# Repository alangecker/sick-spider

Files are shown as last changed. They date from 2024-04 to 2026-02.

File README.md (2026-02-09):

# SICK Spider
A new board design for the amazing [COATI Spider project](https://coati.pimienta.org/electronics/spider/), a small portable device for simultaneous interpretation.

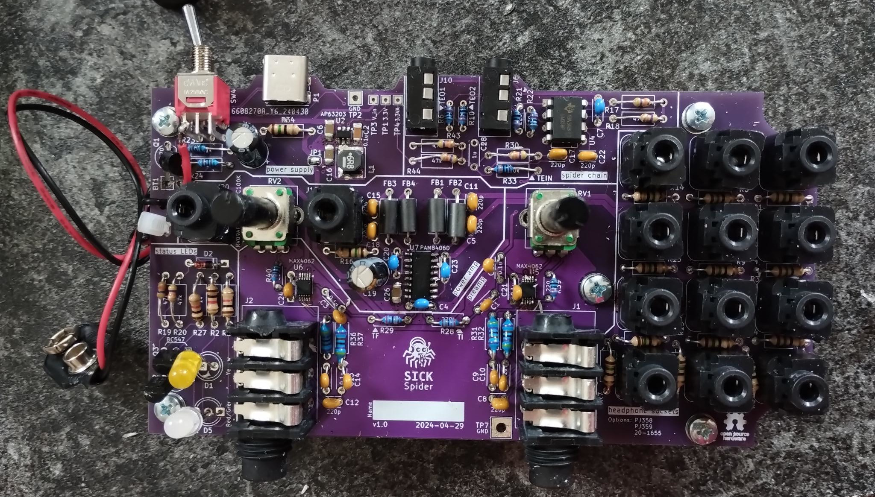
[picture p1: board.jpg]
photo of the finished board with soldered components


## Changes compared to the COATI spider
- way less noise
- battery level indicator
- better gain control range
- USB-C port for power supply
- way longer battery runtime (8-50h)
- easier available components

## Costs
- roughly 20€ for a spider without accessories
- An existing COATI spider case can be reused, only one additional cutout for the USB-C port is required.

## Case
The files for 3D printing a case can be found here:
https://github.com/alangecker/spider-case

## Documents & How-To's

#### Version 1.2 (Documents work in progress)
- [Changelog](./CHANGELOG.md)
- Ordering
  * [Parts list](https://pad.kanthaus.online/sick-spider-parts-list?view)
  * Gerber files: [JLCPCB](https://alangecker.github.io/sick-spider/output/1.2/JLCPCB/spider2-JLCPCB.zip)
- Building instructions
    * [Part 1: soldering “SMD” components](https://pad.kanthaus.online/sick-spider-instructions-part1?view)
    * [Part 2: soldering "trough hole" components](https://pad.kanthaus.online/sick-spider-instructions-part2?view)
- [Debugging](https://pad.kanthaus.online/sick-spider-instructions-debugging?view)
- [Boardview and BOM](https://alangecker.github.io/sick-spider/output/1.2/spider2-ibom.html)
- [Schematic](https://alangecker.github.io/sick-spider/output/1.2/spider2-schematic.pdf)

#### Version 1.1
- [Changelog](./CHANGELOG.md)
- Ordering
  * [Parts list](./docs/v1.1/partslist.md)
  * Gerber files: [JLCPCB](https://alangecker.github.io/sick-spider/output/1.1c/JLCPCB/spider2-JLCPCB.zip)
- Building instructions
    * [Part 1: soldering “SMD” components](./docs/v1.1/part1-smd.md)
    * [Part 2: soldering "trough hole" components](./docs/v1.1/part2-throughhole.md)
- [Boardview and BOM](https://alangecker.github.io/sick-spider/output/1.1c/spider2-ibom.html)
- [Schematic](https://alangecker.github.io/sick-spider/output/1.1c/spider2-schematic.pdf)

#### Version 1.0
- Ordering
  * [Parts list](./docs/v1.0/partslist.md)
  * Gerber files: [JLCPCB](https://alangecker.github.io/sick-spider/output/1.0/JLCPCB/spider2-JLCPCB.zip)
- Building instructions
    * [Part 1: soldering “SMD” components](./docs/v1.0/part1-smd.md)
    * [Part 2: soldering "trough hole" components](./docs/v1.0/part2-throughhole.md)
    * [Part 3: building the case](https://pad.kanthaus.online/sick-spider-instructions-part3?view)
- [Debugging](./docs/v1.0/debugging.md)
- [Boardview and BOM](https://alangecker.github.io/sick-spider/output/1.0/spider2-ibom.html)
- [Schematic](https://alangecker.github.io/sick-spider/output/1.0/spider2-schematic.pdf)

## License
GPLv3 (=open source♥)

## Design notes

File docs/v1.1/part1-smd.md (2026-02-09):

# Part 1: soldering "SMD" components

_SMD_ stands for _surface mounted devices_ and means all (usually quite small) components which don't have legs going through the board.

this requires some soldering skills and you should not do this as your first soldering lesson. rather get help for this part, learn with the through-hole parts and help than the next person with the SMD soldering :)

### Required Tools
- **Soldering iron**
- **Sharp metal tweezers** for holding the components
- **Solder** 
- **Solder wick** for removing excess solder
- **Cotton swab / Q-tips** and
- **Isopropanol** for cleaning up
- **Microscope** if available or Camera with good enough zoom

<!-- 
### How to solder SMD components with solder paste & air gun
There are pleanty of tutorials to find on the internet. If you do it for the first time, maybe watch one first :)
- https://youtube.com/watch?v=rgcupYOnvBo
 -->

### Steps

##### 1.1 PAM8406 Power Amplifier (U7)
1. apply some solder to one corner pad
2. place component onto the place
    * make sure that the dot on the component (= Pin 1) matches the arrow on the board
3. with the soldering iron solder this corner pad
4. with the placement being correct, solder the opposite corner pad
5. with the placement still being correct, solder all other pads 
6. verify, that there are no bridges between contacts, if so
    * add some flux
    * work with the soldering iron and potentially the solder wick to remove the excess solder
7. clean everything with isopropanol
    * there might be tiny solder balls which could short something else
8. under the microscope check every pin, whether it is probably soldered

##### 1.2 OPA2310 Operational Amplifier (U4, U5, U6)
1. repeat process for all 3 op-amps as with the PAM8406

##### 1.3 NCV8114 Linear Regulator for 1.65V (U1)
now with increased soldering skills you can approch the much smaller components!
1. repeat process as with the PAM8406

##### 1.4 AP63203 Step Down Converter for 3.3V (U2)
1. repeat process as with the PAM8406

##### 1.5 Capacitors and coil
1. Solder C6, C16, C26 (22 uF capacitor)
2. Solder C2 (0.1 uF Capacitor)
3. Solder L1 (square coil/inductance)
4. Solder Fuse F1 (250mA)

<!-- ##### 1.6 USB port (J17)
1. place the USB port into the corresponding place
2. solder one leg
3. make sure, that the tiny pins on the back align
4. solder the other legs
5. solder the pins
6. verify, that there are no bridges between contacts, if so
    * add some flux
    * work with the soldering iron and potentially the solder wick to remove the excess solder
7. clean everything with isopropanol
    * there might be tiny solder balls which could short something else
8. under the microscope check every pin, whether it is probably soldered

 -->
##### 1.6 Verify connections
With such tiny components, it is quite easy to get a bad solder joint. Verify them but measuring following values.

1. Wait until board cooled down
2. Put Multimeter into _diode mode_ 
3. Red multimeter probe onto GND
4. With black probe go through all the points on the picture and ensure that the values match
    * if some value does not match, check the solder joints connected to the point



##### 1.7 clean up
1. Clean up once more everything with isopropanol

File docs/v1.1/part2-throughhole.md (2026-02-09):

# Part 2: soldering "trough hole" components
:::danger
this guide is work in progress for version 1.1. some things might be wrong/missing
:::

## generally
- always make sure that the components are as close as possible on the board
    - especially the blue capacitors, which are a bit to big. they still should be pulled to be as close as possible
- cut off the component legs on the bottom side (<5mm)
- when removing components, never use force, since it is quite easy to rip off pads and traces from the board. if something sticks too strong, the solder is probably still not liquid enough!

## 2.0 Your spider
this is your creation, give it a name! :)
1. The spdier name in thr frontside
2. your name on the back

## 2.1 Power supply section
1. Solder 5.1k Ohm resistors (R23, R24)
2. Solder 15 Ohm resistor (R34, R50)
3. Battery clip: pull the cable through the upper hole (see picture) and solder it on (red +; black -)
4. Use a cable tie to secure/relief the battery cable (see picture)
5. Solder USB Port (J17)
    * place the USB port into the corresponding place
    * make sure port sits as close as possible on the board
    * solder one leg
    * make sure, that the tiny pins on the back align
    * solder the other legs
    * solder the pins
6. Solder Power Switch (SW4)
8. Solder reverse polarity transistor BS170 (Q1) 
    * ensure orientation is like shown on the Board 
10. Solder 220uF capacitor (C30, C25)
    * ensure correct orientation
11. Solder 1uF capacitor (C28, C33)
12. go through the following debugging steps (see Debugging)
    * DBG-1
    * DBG-2.1
    * DBG-2.2
    * DBG-2.5
    * DBG-2.7
13. If 3.3V is present, create a solder bridge between the pads from JP1
14. Do test DBG-2.6

#### battery connector

:::danger
the picture is not updated yet. the cable has to end on the top side
:::

 

## 2.2 Status LED section
1. solder 6.2V diode (D2)
2. solder 47k resistor (R19,R20)
3. solder 1k resistor (R27, R2, R25)
4. solder transistor BC547 (Q2, Q3)
    * ensure correct orientation
6. solder yellow LED (D1)
    * short leg goes into the rectangular pad
    * TODO: led distance to board
7. solder red/green battery LED (D5)
8. do tests
    * DBG-2.3
    * DBG-2.4

## 2.3 Preamplifier section
1. solder 4.7k Ohm resistor (R43, R49, R39, R44) Hallo simon :)
2. solder 0.1uF capacitor (C13, C14, C9, C10, C27, C3, C1, C21, C29)
3. solder 220pF capacitor (C12, C8)
4. solder 270k Ohm resistor (R29, R28)
5. solder 10k Ohm resistor (R45, R42, R48, R47, R41, R40, R26, R31, R32, R35, R37, R38)
4. solder 47 Ohm resistor (R46, R36)
6. solder potentiometers (RV1, RV2)
7. solder sockets (J2,J1)
8. do tests: DBG-3

## 2.4 Power amplifier section
1. solder black ferrit beads (FB1-4)
2. solder 220pF capacitor (C15, C18, C11, C5)
3. solder 1uF capacitor (C20, C23, C4)
4. solder 220uF electrolytic capacitor (C19)
    * ensure correct orientation
5. do tests DBG-4

## 2.5 Headphone sockets
1. solder 15 Ohm resistor for floor headphones (R16)
2. solder all 15 Ohm resistors in the headphone section
3. solder all headphone sockets
    * **Important:** only use the minimal amount of solder required, otherwise it will flow into the socket and create a short circuit
    * they need to be as close as possible to the board
    * it is quite difficult to solder with only 2 hands, feel free to ask others for support :)
4. check, whether all pins of all headphone sockets are soldered
5. test all headphone sockets

## 2.6 Spider chain section
1. solder 47k ohm resistor (R33, R30)
2. Solder 0.1u capacitator (C17 & C7)
  * **Important:** with Version 1.1b the C7 capacitor needs to be soldered between the left pad and directly to Pin 4 of U4 
4. solder 220 ohm resistor (R6, R10, R21, R22)
5. solder 10k ohm resistor (R17, R18)
6. solder 220pF capacitor (C17)
8. solder headphone sockets (J10, J6)
9. do tests DBG-5

## 2.7 finishing up
1. clean up all flux with isopropanol
2. have a second look on all solder joints

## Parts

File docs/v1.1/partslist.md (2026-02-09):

# SICK Spider v1.2: parts list

### Resistors

Count| Value    | Color     | Note      | Links
----:|----------|----------|-----------|---------
   4 | 4.7k     | 🟨🟪🟫⬛ 🟪 |0.1%      | [Mouser](https://www.mouser.de/ProductDetail/603-MFP-25BRD52-4K7) 
   2 | 270k     | 🟥🟪⬛🟧   |         | [Mouser](https://www.mouser.de/ProductDetail/603-MFR-12FTF52-270K) 
   2 | 5.1k     | 🟩🟫⬛🟫   |         | [Mouser](https://www.mouser.de/ProductDetail/603-MFR-12FTF52-5K1) 
   4 | 47k      | 🟨🟪🟧     |         | [Mouser](https://www.mouser.de/ProductDetail/603-CFR25SJT-52-47K) 
   4 | 220      | 🟥🟥⬛⬛   |1%, L3.6mm| [Mouser](https://www.mouser.de/ProductDetail/603-MFR25SFTF52-220R) 
   3 | 1k       | 🟫⬛🟥     |         | [Mouser](https://www.mouser.de/ProductDetail/708-CF18JT1K00)
  15 | 15       | 🟫🟩⬛     |         | [Mouser](https://www.mouser.de/ProductDetail/603-CFR-25JR-52-15R)
  14 | 10K      | 🟫⬛🟧🟫 | 1%, L3.6mm | [Mouser](https://www.mouser.de/ProductDetail/603-MFR25SFTF52-10K)
   2 | 47       | 🟨🟪⬛ | L3.6mm | [Mouser](https://www.mouser.de/ProductDetail/603-CFR-12JR-52-47R)

### Capacitors
Count| Value     | Note          | Links
----:| ----------|---------------|----------
   3 | 220u      | D6.3mm, P2.5mm, 6.3V | [Mouser](https://www.mouser.de/ProductDetail/667-ECE-A0JKA221)
   7 | 220p      | P2.5mm        | [Mouser](https://www.mouser.de/ProductDetail/594-K221K10X7RF5TL2)
   5 | 1u        | P2.5mm        | [Mouser](https://eu.mouser.com/ProductDetail/810-FG18X7R1E105KRT6)
   10 | 0.1u      | ≥16V, P2.5m   | [Mouser](https://www.mouser.de/ProductDetail/594-K104K10X7RF5TL2)
   3 | 22u       | SMD 1206      | [Mouser](https://www.mouser.de/ProductDetail/187-CL31A226MOCLNNC)
   1 | 0.1u      | SMD 1206, ≥20V| [Mouser](https://www.mouser.de/ProductDetail/80-C1206C104K5R7210)

### Diodes
Count| Component       | Note       | Links
----:| ----------------|------------|--------
   1 | [LED Red/Green](https://eu.mouser.com/datasheet/2/216/WP59EGW-CA-54724.pdf) | common anode | [Mouser](https://www.mouser.de/ProductDetail/604-WP59EGW-CA)
   1 | LED Yellow      |            | [Mouser](https://www.mouser.de/ProductDetail/604-WP1503YD)
   1 | Zener 6.2V      |            | [Mouser](https://www.mouser.de/ProductDetail/78-1N5234B)

### Integrated circuits
Count| Component  | Note| Links 
----:| ---------- |----|--------
   1 | [PAM8406D](https://www.diodes.com/assets/Datasheets/PAM8406.pdf) | | [Mouser](https://www.mouser.de/ProductDetail/621-PAM8406DR), [Digikey](https://www.digikey.com/en/products/detail/diodes-incorporated/PAM8406DR/4033289)
   3 | [OPA2310](https://www.ti.com/lit/ds/symlink/opa2310.pdf) |  SOIC-8 | [Mouser](https://www.mouser.de/Search/Refine?Keyword=595-OPA2310IDR)
   1 | [AP63203](https://www.diodes.com/assets/Datasheets/AP63200-AP63201-AP63203-AP63205.pdf) | | [Mouser](https://www.mouser.de/ProductDetail/621-AP63203WU-7)
   1 | [NCV8114ASN165](https://www.onsemi.com/download/data-sheet/pdf/ncv8114-d.pdf) | | [Mouser](https://www.mouser.de/Search/Refine?Keyword=863-NCV8114ASN165T1G)

### Transistors
Count| Component      | Note       | Links
----:| ----------------|------------|--------
   2 | [BC547](https://diotec.com/request/datasheet/bc546.pdf) |   | [Mouser](https://www.mouser.de/ProductDetail/637-BC547C)
   1 | [BS170](https://www.onsemi.com/pub/Collateral/BS170-D.PDF) | wide leads (D) | [Mouser](https://www.mouser.de/ProductDetail/512-BS170D75Z)

## Inductors
Count| Component       | Note                 | Links
----:| ----------------|----------------------|--------
   4 | Ferrite Bead    | ≥2A, ≥100 Ohm@100Mhz, axial | [Mouser](https://www.mouser.de/ProductDetail/623-2743003111)
   1 | Inductor 6.8uH  | ≥1A, <100mOhm, SMD 4.9mm | [Mouser](https://www.mouser.de/ProductDetail/963-NRS5040T6R8MMGJ)

### Electromechanical (Poti, Switches, Connectors)
Count| Component  | Links | Alternatives
----:| ---------- |--------|-------------
   2 | [RV09AF-40-30K-C10K](https://www.mouser.de/datasheet/2/13/RV09AF-2303609.pdf) | [Mouser](https://www.mouser.de/ProductDetail/317-3090F-10K) | 
   1 | [200MDP3T1B1M6QE](https://eu.mouser.com/datasheet/2/140/200-3304369.pdf) | [Mouser](https://www.mouser.de/ProductDetail/612-200MDP3T1B1M6QE) | 200MDP3T\*\*\*M6Q
   1 | [USB4125](https://www.mouser.de/datasheet/2/837/GCT_usb4085-3240028.pdf) | [Mouser](https://www.mouser.de/ProductDetail/640-USB4125-GF-A-190) | 
   2 | [PJ-320A](https://wmsc.lcsc.com/wmsc/upload/file/pdf/v2/lcsc/2311241628_Hong-Cheng-HC-PJ-320A_C7501806.pdf) | [Aliexpress](https://www.aliexpress.com/item/32368285821.html) | 
  14 | [PJ358](https://wmsc.lcsc.com/wmsc/upload/file/pdf/v2/lcsc/2201201600_HOOYA-PJ-358_C2939193.pdf)      | [Aliexpress](https://www.aliexpress.com/item/1005001463970178.html) | PJ359, TruConnect 20-1655
   2 | [NRJ6HH-1](https://www.neutrik.com/en/product/nrj6hh-1) | [Mouser](https://www.mouser.de/ProductDetail/568-NRJ6HH-1) | NRJ6HH, ACJS-HHOP-1
   1 | 9V Battery Connector | [Mouser](https://www.mouser.de/ProductDetail/534-234) | 

### Other
Count| Component      | Note       | Links
----:| ----------------|------------|--------
   1 | 250mA fuse    | SMD 1206  | 

### Mechanical
Count| Component  | Note  | Links |
----:| ---------- |-------|--------|
   2 | Knobs           | 6mm        |  | 
   1 | cable ties      | 2-3mm x 50-100mm | 
   1 | 3D printed case |   | https://github.com/alangecker/spider-case
   5 | 3x20 wood screws

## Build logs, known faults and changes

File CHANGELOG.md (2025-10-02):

# SICK Spider changelog

## Version 1.2
- replace expensive switch (200MDP3T1B1M6QE, 3-4€) by a much cheaper on (SK-23D07, ~10ct)

## Version 1.1c
- Fix misaligned traces at C16, C7 and C24
- Add missing Silkscreen value for C29
- Power switch 1mm further inside (sticks out quite a lot)
- more clearence for headphone jacks so that it is more difficult to bridge them to GND

## Version 1.1b
- Limit Microphone Gain (R36,R46)
- Battery fuse
- More room for soldering USB port
- Correct footprints for 0.1uF capacitors
- Correct footprints for 4.7k resistor

## Version 1.1
- replace MAX4062 with own preamplifier circuit in order to avoid difficult TSOP soldering
- Fix wrong footprints for 20-1655 headphone jacks
- thicker traces to reduce the chance of irreparable damage by ripping them off
- easier solderable USB-C port
- add linear regulator for stable 1.65V
- replace LM358 with rail-to-rail and 3.3V compatible OPA2310 op amp
- rounded corners
- Remove PJ359 footprints (won't use them anymore)
- label switch positions (BAT / USB) on the board

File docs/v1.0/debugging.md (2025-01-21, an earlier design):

# Debugging issues
_only valid for SICK Spider version 1.0_

## Required Tools
- something outputting a sinus signal on a 2-pin 6.3mm Jack cable, either
    * Smartphone or Laptop with
        - a 2-Pin ("TS") 3.5mm -> 6.3mm Jack cable (e.g. https://www.thomann.de/intl/the_sssnake_adapter_cable_6_3_3.5_mm.htm)
        - https://draemm.li/various/tonegen/
        - with set to full volume the spider could already distort, maybe rather put it to 50%
    * Signal generator
        - 440 Hz
        - 1V (signal should not distort until 1.3V)
- XLR -> TRS Jack cable
- USB-C Power supply
- 9V Battery (full)
- Multimeter
- Oscilloscope

## DBG-1 Short circuits
Set Switch to "USB" (to the left / away from the usb port) and measure resistance between following points, all values should be >10 kOhm. You can find the points next to the USB Port.
1. GND and Vin (TP3)
1. GND and 3.3V (TP1)
1. GND and 3.3VA (TP4)

## DBG-2 Power supply
1. Plug in USB, set switch to USB (left) and measure voltage between GND and V_in (TP3). it should around 5V. If not
   * check the USB power supply
   * check solder joints on P1, SW4
2. Plug in a Battery, set switch to Battery (right) and measure voltage between GND and V_in (TP3). it should be between 5V and 9V (depending on the battery state) if not
   * check battery voltage
   * check orientation of the battery connector BT1 (red should go to +)
   * check orientation of MOSFET Q1
3. The ON-LED (D1) should light up. if not
   * check solder joints on D1, R2
   * check orientation of LED (D1)
4. With a battery the battery status LED (D5) should light up. if not
   * check all solder joints in the status LED section
   * check orientation of LED (D5), diode (D2) and transistors (Q2,Q3)
5. Verify with a battery 3.3V between GND and TP1 if not
   * check orientation of U2
   * check all solder joints of the SMD components in the power supply section
   * it still not working, U2 might be broken and needs to be replaced
6. Check with a battery for 3.3V at TP4 (3.3VA)
   * check solder bridge JP1
   * check solder joints of R34

## DBG-3 Preamp
1. Floor input (left): Set volume potentiometer as low as possible, plug in a sinus signal (see "Required tools"). With an oscilloscope confirm a sinus signal between R29 (at the arrow) and GND, if not
  * check all solder joints at U6, potentially bridged between two pins
  * check all solder joints in that area
  * check for 3.3V on C21
2. Sinus wave on oscilloscope should in-/decrease with raising/lowering the volume potentiometer, if not
  * check all solder joints on potentiometer
  * check the two most right solder joints on U6
3. Repeat the same for the interpreter input (right) on R28
  * check all solder joints on potentiometer
  * check the two most right solder joints on U5

## DBG-4 Power Amplifier
1. Disconnect any input and measure the DC voltage at every ferrit bread (FB1-4) against GND. it should be 1.6-1.8V, if not
    * check all solder joints on U7 and ferrit breads
    * replace U70 
2. Connect a sinus signal to the floor input (left) and measure the DC voltage across FB3 ↔ FB4. it should be <30mV, if not
    * // TODO
3. Measure AC voltage across FB3 and FB4. it should be >0.3V and in-/decrease with the volume potentiometer
    * // TODO
4. Repeat step 2 with interpreter input and DC voltage across FB1 ↔ FB2
5. Repeat step 3 with interpreter input and AC voltage across FB1 ↔ FB2

## DBG-5 spider chain

:::info

**TODO**
:::

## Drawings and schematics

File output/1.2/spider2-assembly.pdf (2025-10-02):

# U7 PAM8406D ²²⁰ R6

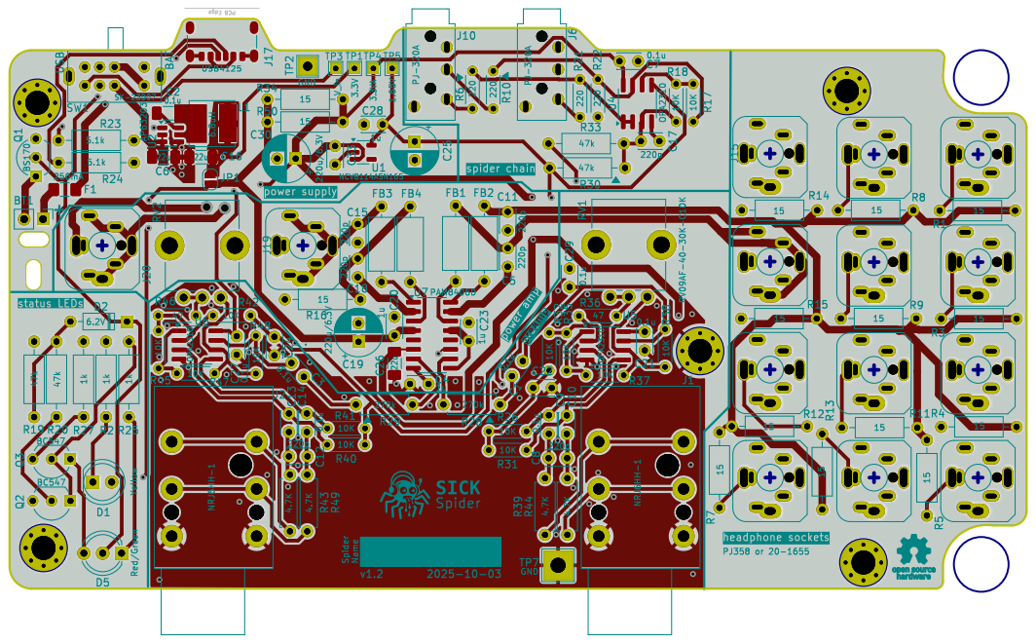
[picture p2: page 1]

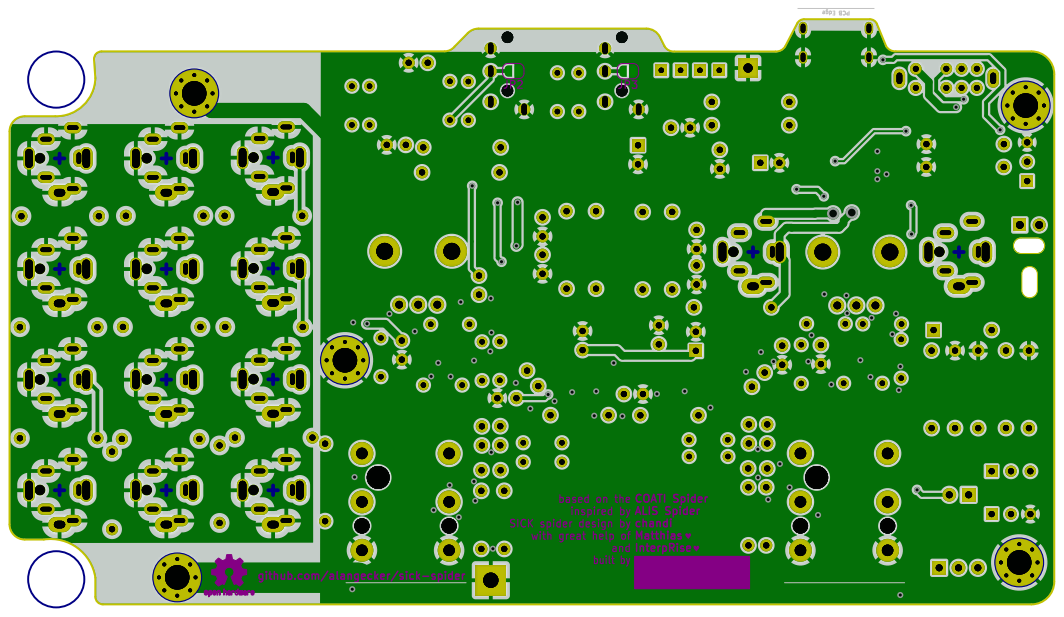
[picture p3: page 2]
File:; spider2.kicad_pcb; built by; and; InterpRise; Matthias; chandi; ALIS Spider; COATI Spider

based on the
inspired by

SICK spider design by
with great help of

github.com/alangecker/sick-spider

Sheet: Bottom copper
Title:

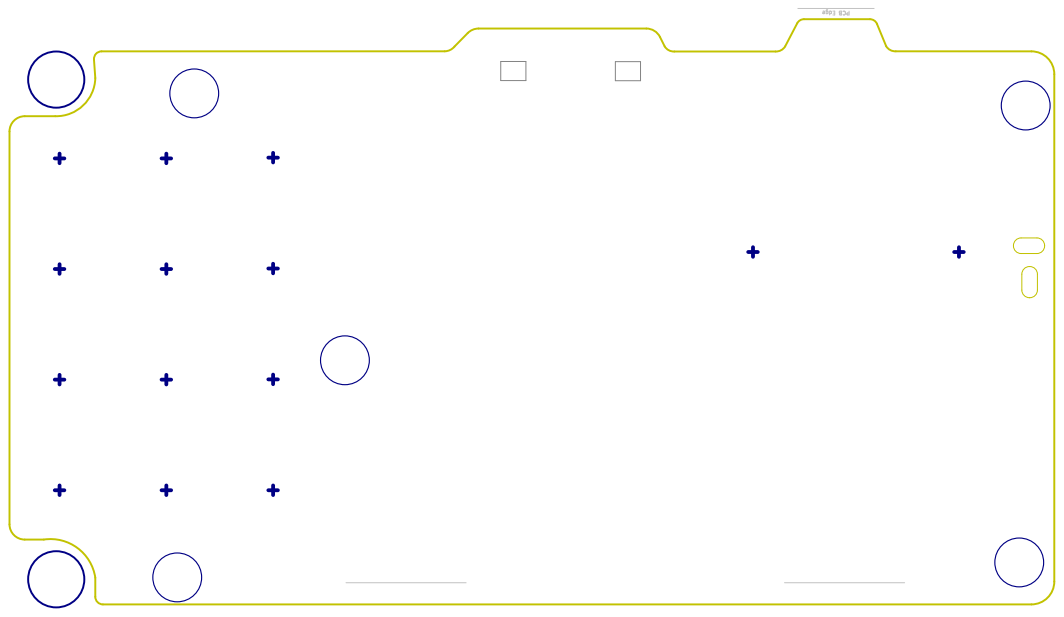
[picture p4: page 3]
Sheet:; Bottom courtyard area; File:; spider2.kicad_pcb; Title:

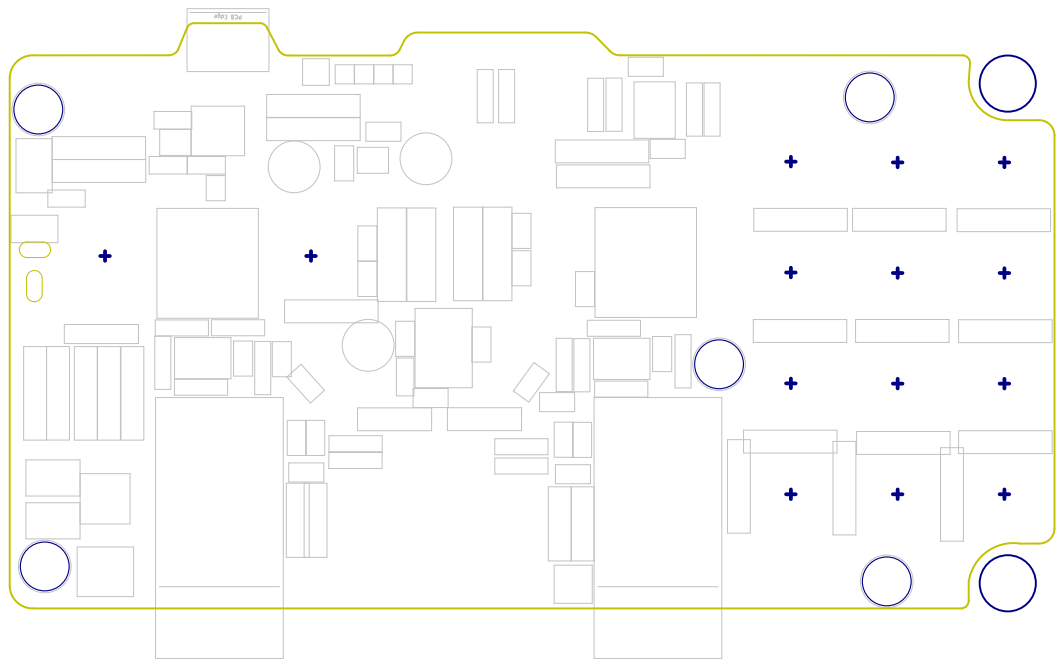
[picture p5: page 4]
Sheet:; Front courtyard area; File:; spider2.kicad_pcb; Title:

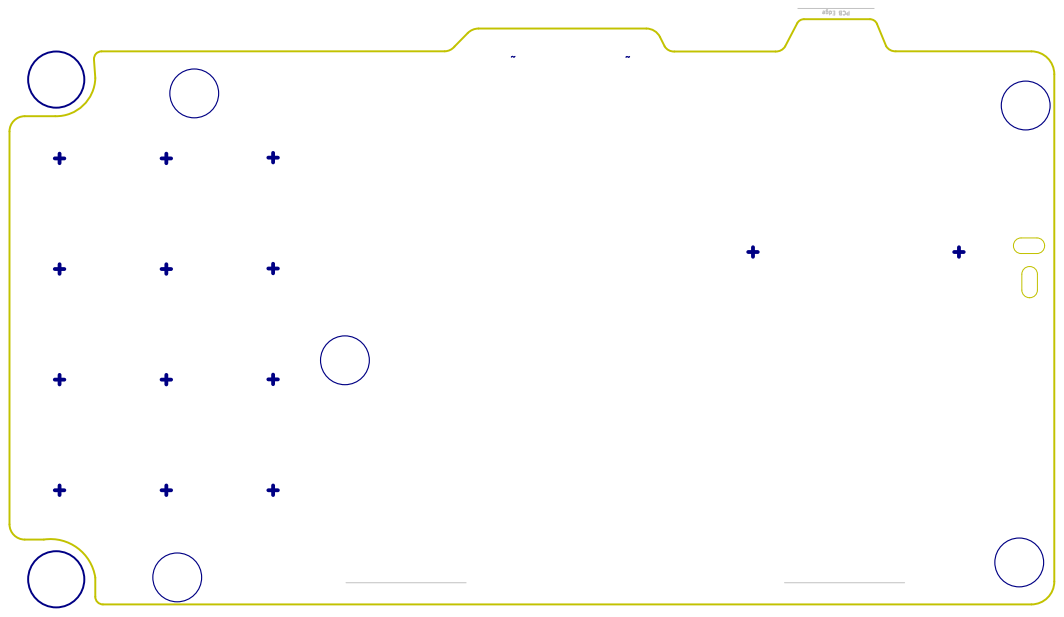
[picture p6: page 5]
Sheet:; Bottom documentation; File:; spider2.kicad_pcb; Title:

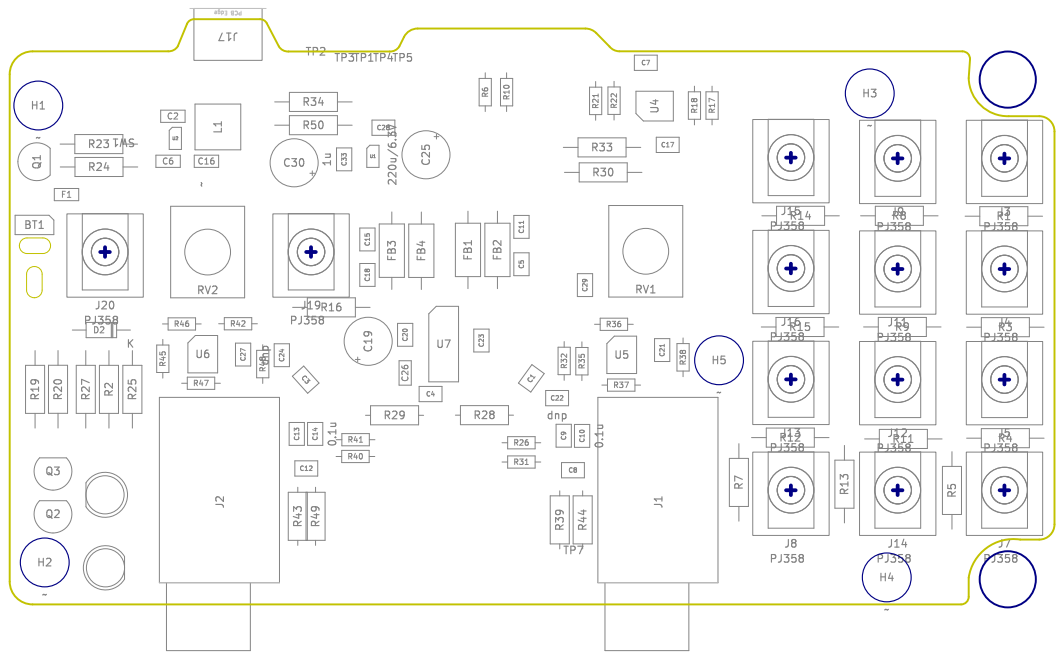
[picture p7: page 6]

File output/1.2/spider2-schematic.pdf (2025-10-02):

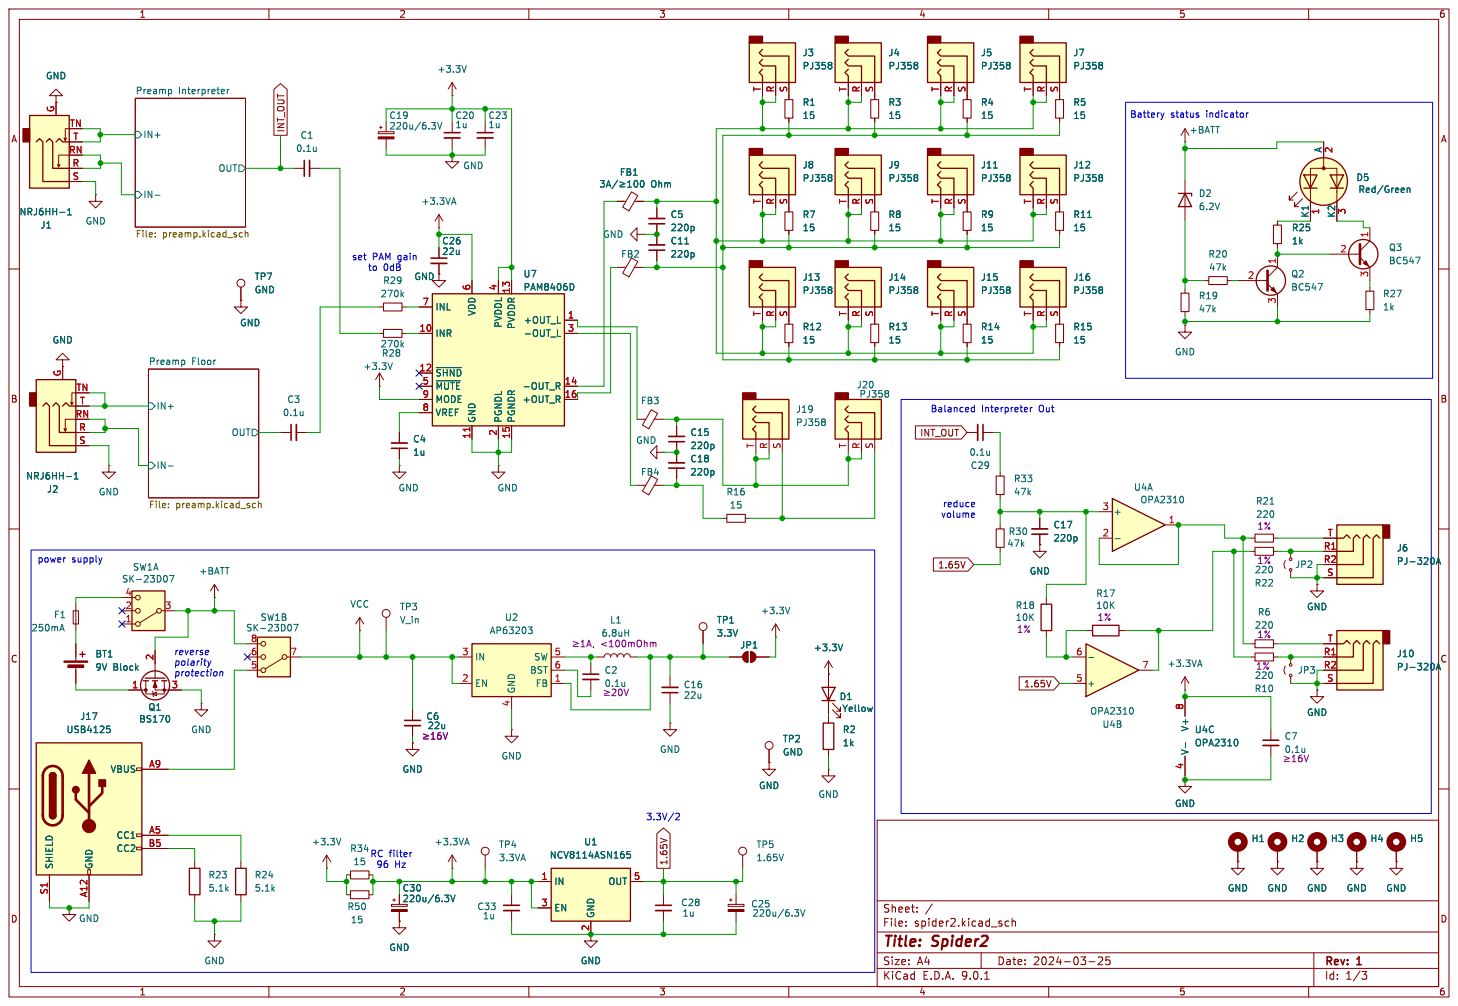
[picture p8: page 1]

volume RC filter 96 Hz

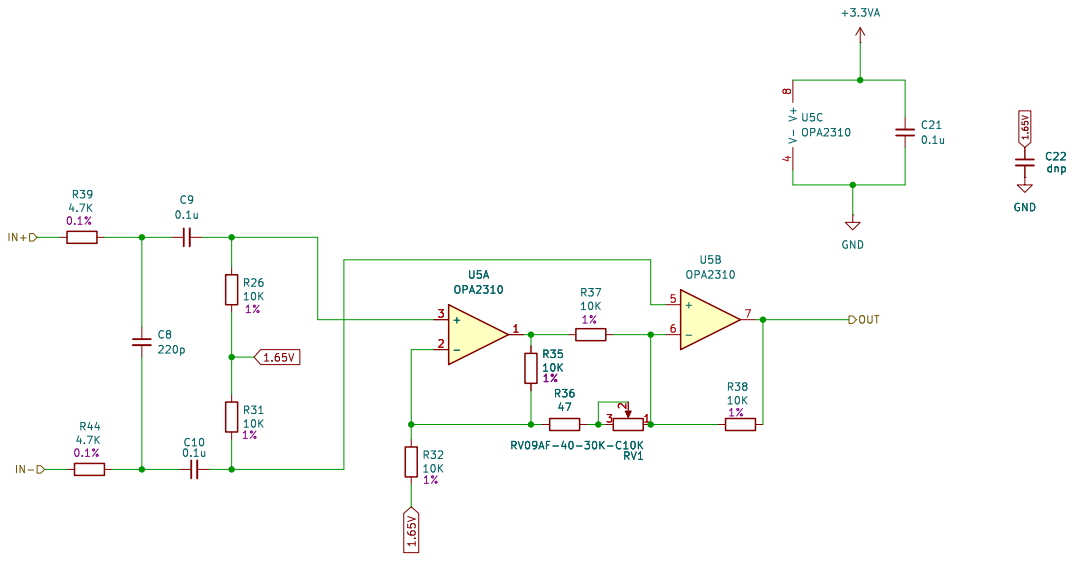
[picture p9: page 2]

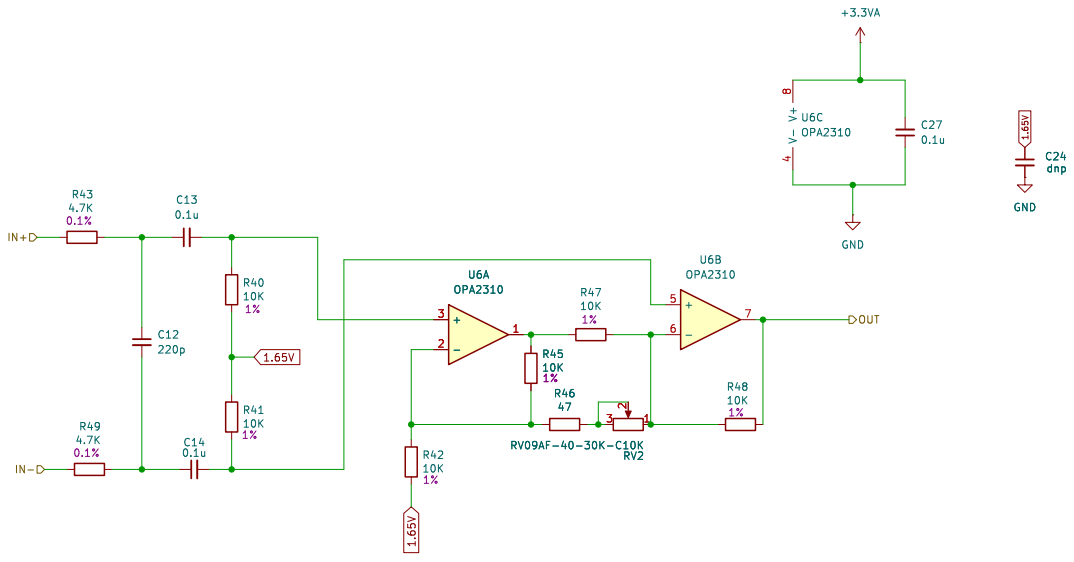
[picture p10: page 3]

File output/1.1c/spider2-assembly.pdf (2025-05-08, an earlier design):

# U7 PAM8406D ²²⁰ R6

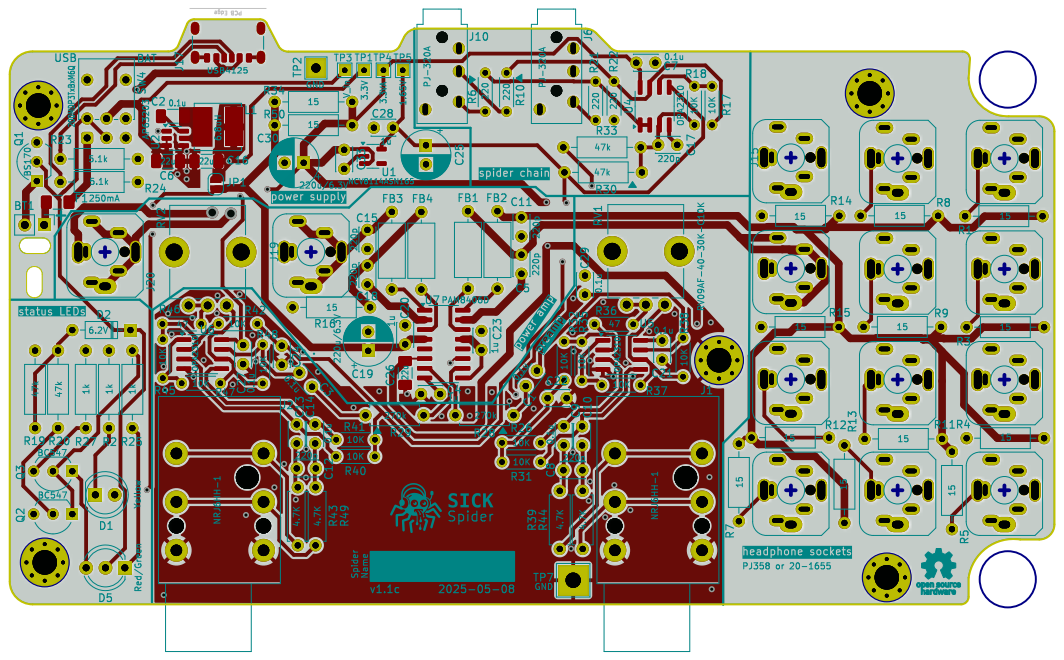
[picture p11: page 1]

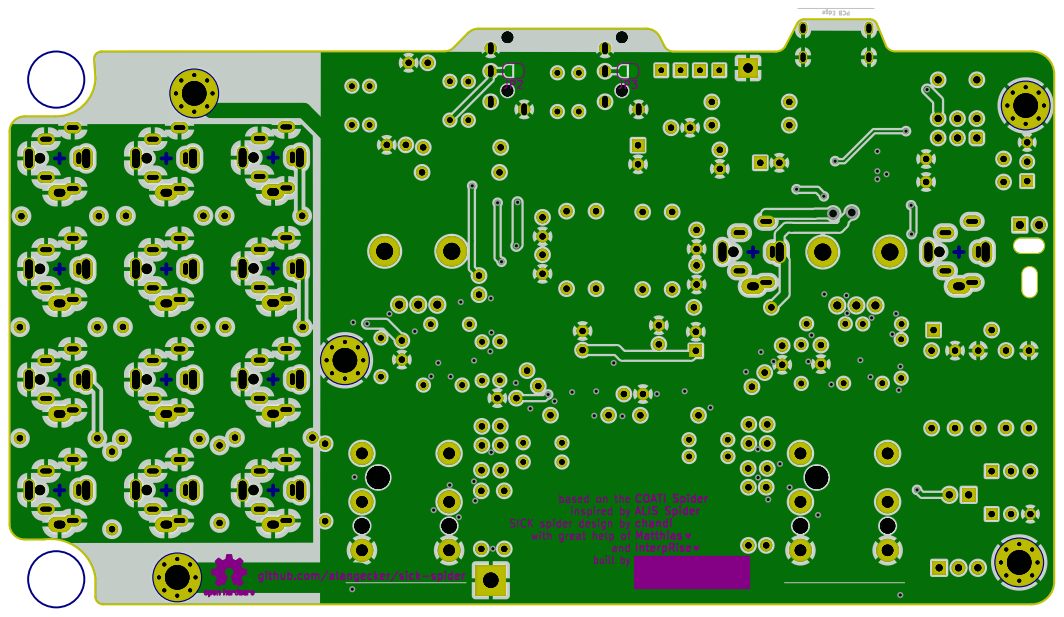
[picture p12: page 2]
File:; spider2.kicad_pcb; built by; and; InterpRise; Matthias; chandi; ALIS Spider; COATI Spider

based on the
inspired by

SICK spider design by
with great help of

github.com/alangecker/sick-spider

Sheet: Bottom copper
Title:

Sheet:; Bottom courtyard area; File:; spider2.kicad_pcb; Title:

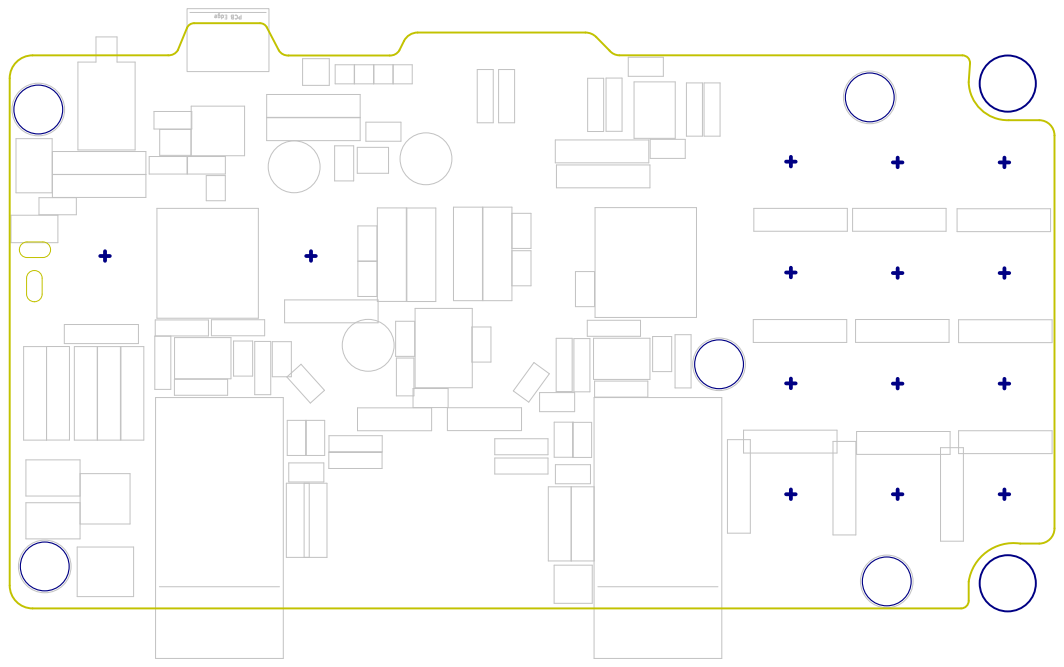
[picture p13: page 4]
Sheet:; Front courtyard area; File:; spider2.kicad_pcb; Title:

Sheet:; Bottom documentation; File:; spider2.kicad_pcb; Title:


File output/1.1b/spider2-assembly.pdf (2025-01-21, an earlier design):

A

A


A

A

Sheet:; File: spider2.kicad_pcb Title:; built by; and; InterpRise; Matthias; chandi; ALIS Spider; COATI Spider

based on the
inspired by

SICK spider design by
with great help of

github.com/alangecker/sick-spider

A

A

Sheet:; File: spider2.kicad_pcb Title:

A

A

Sheet:; File: spider2.kicad_pcb Title:

A

A

Sheet:; File: spider2.kicad_pcb Title:

1

2


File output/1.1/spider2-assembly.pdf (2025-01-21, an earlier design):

1

2


A

A

Sheet: File: spider2.kicad_pcb Title:; built by; and; InterpRise; Matthias; chandi; ALIS Spider; COATI Spider

based on the
inspired by

SICK spider design by
with great help of

github.com/alangecker/sick-spider

A

A

Sheet: File: spider2.kicad_pcb Title:

A

A

Sheet: File: spider2.kicad_pcb Title:

A

A

Sheet: File: spider2.kicad_pcb Title:

1

2


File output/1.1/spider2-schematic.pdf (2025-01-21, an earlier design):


2 EN 3 OUT 5 GND GND

2 EN 3 OUT 5 U1 NCV8114ASN165 GND GND



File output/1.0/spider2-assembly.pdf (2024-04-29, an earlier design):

# U7 PAM8406D ²²⁰ R6


Title:; File: spider2.kicad_pcb; Sheet:; Bottom copper; PCB Edge; built by; and; InterpRise; Matthias; chandi; ALIS Spider; COATI Spider

based on the
inspired by

SICK spider design by
with great help of

github.com/alangecker/sick-spider

Title:; File: spider2.kicad_pcb; Sheet:; Bottom courtyard; area; PCB Edge

Title:; File: spider2.kicad_pcb; Sheet:; Front courtyard area; PCB Edge

Title:; File: spider2.kicad_pcb; Sheet:; Bottom documentation; PCB Edge; C27 dnp; C42 dnp TP6; AUX_IN

# TP4TP1 C20


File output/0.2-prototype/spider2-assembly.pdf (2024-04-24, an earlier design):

# FB1 RV1 100n C9

# U7 PAM8406D ²²⁰⁻¹% R6


github.com/alangecker/sick-spider

Title:; File: spider2.kicad_pcb; Sheet:; Bottom copper; PCB Edge; built by; and; InterpRise; Matthias; chandi; ALIS Spider; COATI Spider

based on the
inspired by

SICK spider design by
with great help of

Title:; File: spider2.kicad_pcb; Sheet:; Bottom courtyard; area; PCB Edge

Title:; File: spider2.kicad_pcb; Sheet:; Front courtyard area; PCB Edge

Title:; File: spider2.kicad_pcb; Sheet:; Bottom documentation; PCB Edge; AUX_IN














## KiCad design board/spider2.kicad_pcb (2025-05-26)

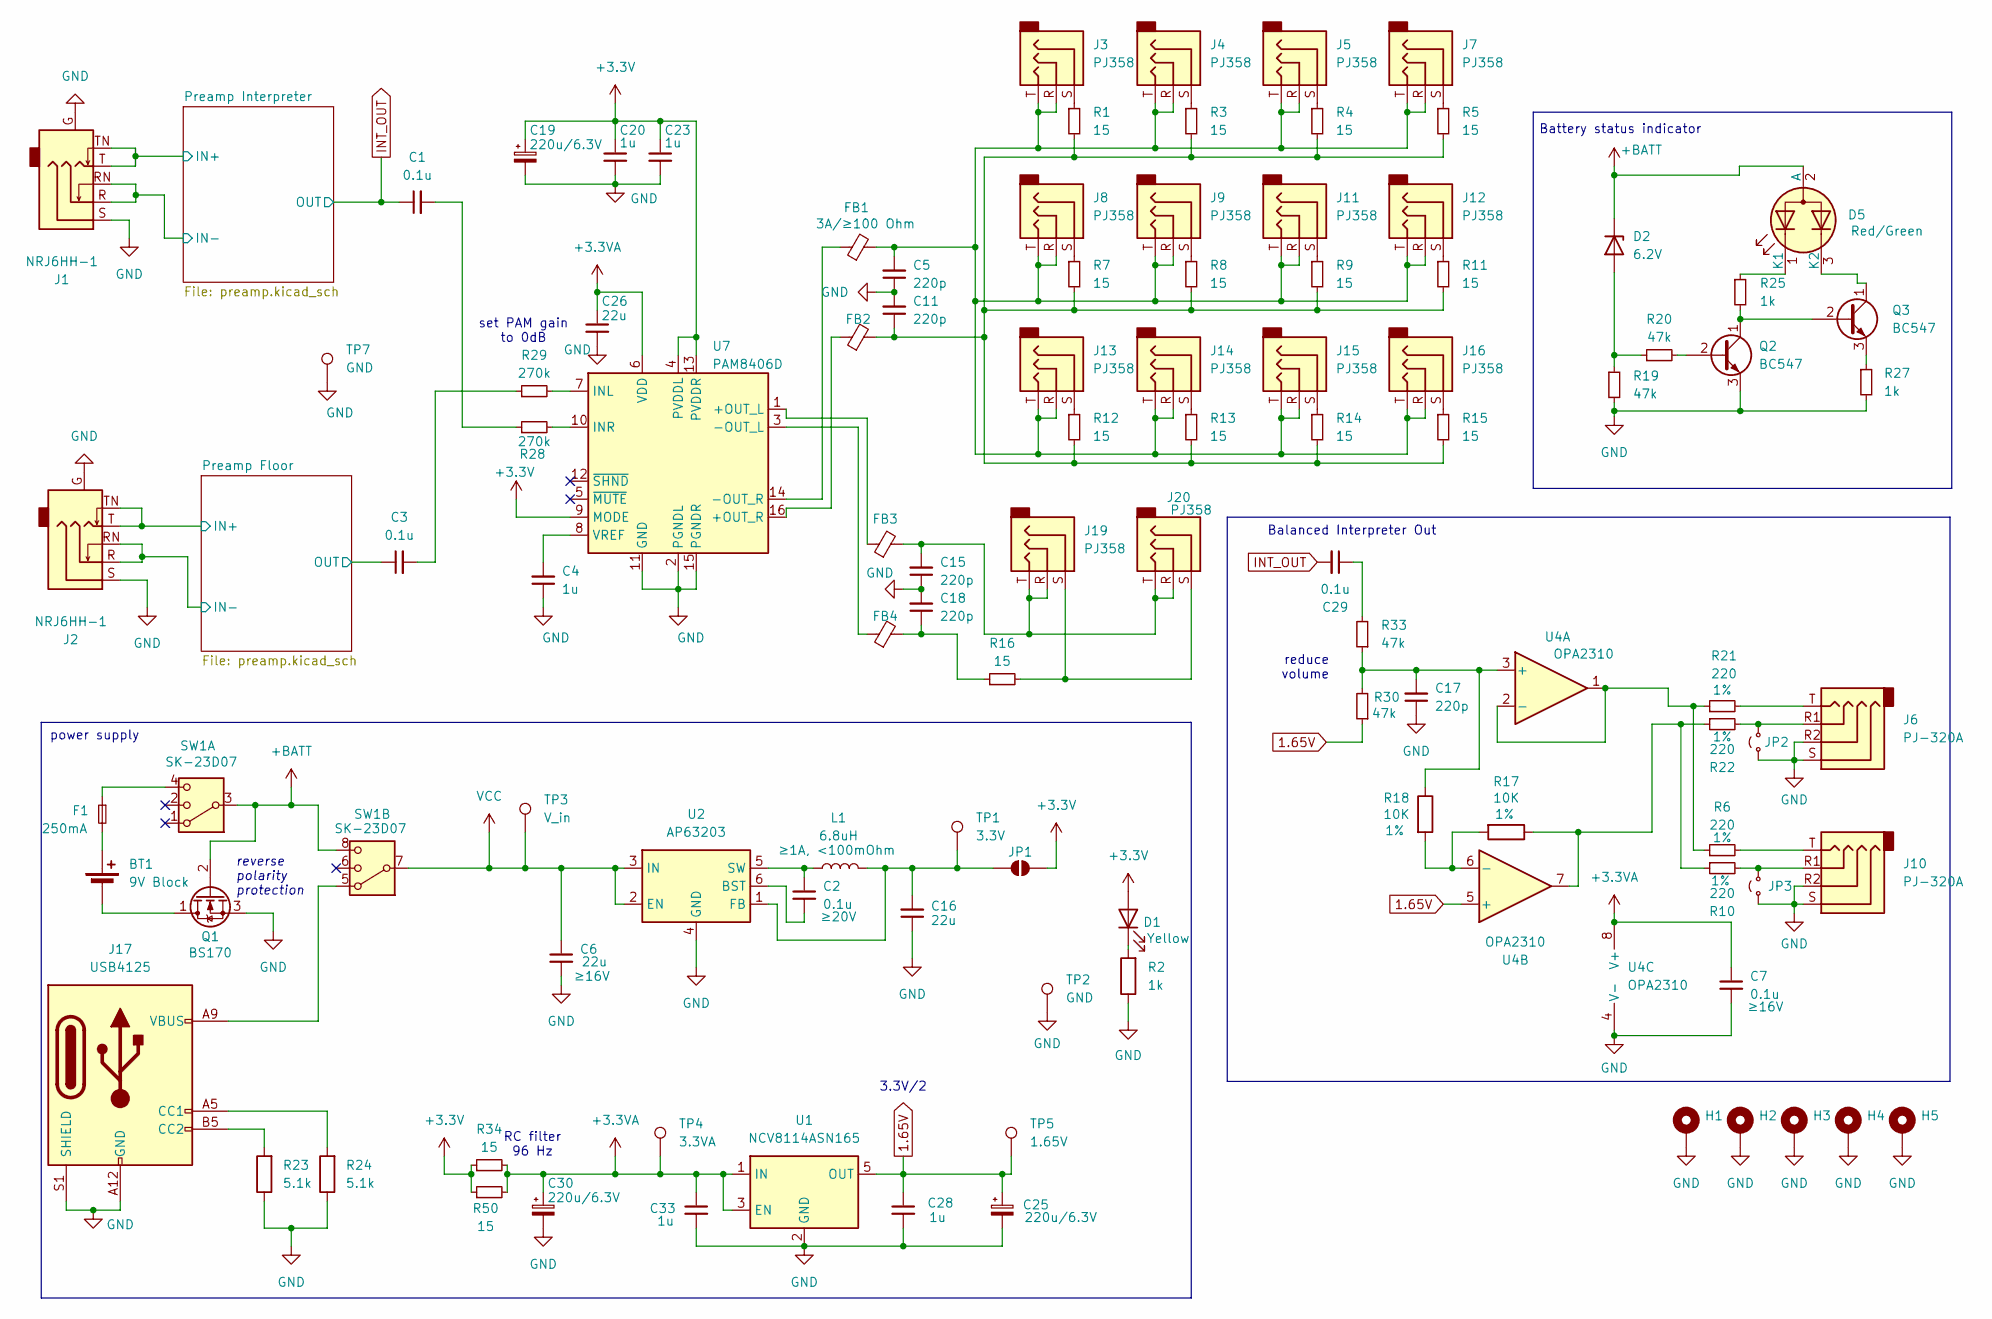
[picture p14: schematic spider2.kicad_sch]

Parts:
BT1: 9V Block; PinHeader_1x02_P2.54mm_Vertical
C1, C3, C7, C29: 0.1u; C_Disc_D3.0mm_W2.0mm_P2.50mm
C2: 0.1u; C_1206_3216Metric_Pad1.33x1.80mm_HandSolder
C4, C20, C23, C28, C33: 1u; C_Disc_D3.0mm_W2.0mm_P2.50mm
C5, C11, C15, C17, C18: 220p; C_Disc_D3.0mm_W2.0mm_P2.50mm
C6, C16, C26: 22u; C_1206_3216Metric_Pad1.33x1.80mm_HandSolder
C19, C25, C30: 220u/6.3V; CP_Radial_D6.3mm_P2.50mm
D1: Yellow; LED_D5.0mm_FlatTop
D2: 6.2V; D_DO-35_SOD27_P7.62mm_Horizontal
D5: Red/Green; LED_D5.0mm-3
F1: 250mA; Fuse_1206_3216Metric_Pad1.42x1.75mm_HandSolder
FB1, FB2, FB3, FB4: 3A/≥100 Ohm; L_Axial_L7.0mm_D3.3mm_P10.16mm_Horizontal_Fastron_MICC
H1, H2, H3, H4, H5: MountingHole_3.2mm_M3_Pad_Via
J1, J2: NRJ6HH-1; Jack_6.35mm_Neutrik_NRJ6HH-1_Horizontal
J3, J4, J5, J7, J8, J9, J11, J12, J13, J14, J15, J16, J19, J20: PJ358; Jack_3.5mm_Hybrid_PJ358_20-1655
J6, J10: PJ-320A; Jack_3.5mm_PJ320A
J17: USB4125; USB_C_Receptacle_GCT_USB4125-xx-x_6P_TopMnt_Horizontal
JP1, JP2, JP3: SolderJumper-2_P1.3mm_Open_RoundedPad1.0x1.5mm
L1: 6.8uH; L_Bourns_SRN6045TA
Q1: BS170; TO-92_Inline_Wide
Q2, Q3: BC547; TO-92_Inline_Wide
R1, R3, R4, R5, R7, R8, R9, R11, R12, R13, R14, R15, R16, R34, R50: 15; R_Axial_DIN0207_L6.3mm_D2.5mm_P10.16mm_Horizontal
R2, R25, R27: 1k; R_Axial_DIN0207_L6.3mm_D2.5mm_P10.16mm_Horizontal
R6, R10, R21, R22: 220; R_Axial_DIN0204_L3.6mm_D1.6mm_P5.08mm_Horizontal
R17, R18: 10K; R_Axial_DIN0204_L3.6mm_D1.6mm_P5.08mm_Horizontal
R19, R20, R30, R33: 47k; R_Axial_DIN0207_L6.3mm_D2.5mm_P10.16mm_Horizontal
R23, R24: 5.1k; R_Axial_DIN0207_L6.3mm_D2.5mm_P10.16mm_Horizontal
R28, R29: 270k; R_Axial_DIN0207_L6.3mm_D2.5mm_P7.62mm_Horizontal
SW1: SK-23D07
TP1: 3.3V; TestPoint_THTPad_1.5x1.5mm_Drill0.7mm
TP2: GND; TestPoint_THTPad_2.5x2.5mm_Drill1.2mm
TP3: V_in; TestPoint_THTPad_1.5x1.5mm_Drill0.7mm
TP4: 3.3VA; TestPoint_THTPad_1.5x1.5mm_Drill0.7mm
TP5: 1.65V; TestPoint_THTPad_1.5x1.5mm_Drill0.7mm
TP7: GND; TestPoint_THTPad_4.0x4.0mm_Drill2.0mm
U1: NCV8114ASN165; TSOT-23-5
U2: AP63203; TSOT-23-6
U4: OPA2310; SOIC-8_3.9x4.9mm_P1.27mm
U7: PAM8406D; SOP-16_3.9x9.9mm_P1.27mm

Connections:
1.65V: C25.1, C28.1, R30.1, TP5.1, U1.5 (OUT), U4.5 (+); also elsewhere on the board
+3.3V: C19.1, C20.1, C23.1, D1.2 (A), JP1.2 (B), R34.1, R50.1, U7.4 (PVDDL), U7.9 (MODE), U7.13 (PVDDR)
+3.3VA: C7.1, C26.1, C30.1, C33.1, R34.2, R50.2, TP4.1, U1.1 (IN), U1.3 (EN), U4.8 (V+), U7.6 (VDD); also elsewhere on the board
+BATT: D2.1 (K), D5.2 (A), Q1.2 (G), SW1.3, SW1.8
/Preamp Floor/IN+: J2.T, J2.TN; also elsewhere on the board
/Preamp Floor/IN-: J2.R, J2.RN; also elsewhere on the board
/Preamp Floor/OUT: C3.1; also elsewhere on the board
/Preamp Interpreter/IN+: J1.T, J1.TN; also elsewhere on the board
/Preamp Interpreter/IN-: J1.R, J1.RN; also elsewhere on the board
GND: C4.1, C5.1, C6.2, C7.2, C11.2, C15.1, C16.1, C17.1, C18.2, C19.2, C20.2, C23.2, C25.2, C26.2, C28.2, C30.2, C33.2, H1.1, H2.1, H3.1, H4.1, H5.1, J1.G, J1.S, J2.G, J2.S, J6.R2, J6.S, J10.R2, J10.S, J17.A12 (GND), J17.B12 (GND), J17.S1 (SHIELD), JP2.1 (A), JP3.1 (A), Q1.3 (S), Q2.3 (E), R2.1, R19.2, R23.1, R24.1, R27.2, TP2.1, TP7.1, U1.2 (GND), U2.4 (GND), U4.4 (V-), U7.2 (PGNDL), U7.11 (GND), U7.15 (PGNDR); also elsewhere on the board
INT_OUT: C1.1, C29.2; also elsewhere on the board
unnamed: BT1.1 (+), F1.2
unnamed: BT1.2 (-), Q1.1 (D)
unnamed: C1.2, R28.1
unnamed: C3.2, R29.1
unnamed: C5.2, FB1.2, J3.R, J3.T, J4.R, J4.T, J5.R, J5.T, J7.R, J7.T, J8.R, J8.T, J9.R, J9.T, J11.R, J11.T, J12.R, J12.T, J13.R, J13.T, J14.R, J14.T, J15.R, J15.T, J16.R, J16.T
unnamed: C11.1, FB2.2, R1.2, R3.2, R4.2, R5.2, R7.2, R8.2, R9.2, R11.2, R12.2, R13.2, R14.2, R15.2
unnamed: C15.2, FB3.2, J19.R, J19.T, J20.R, J20.T
unnamed: C18.1, FB4.2, R16.1
unnamed: C29.1, R33.2
unnamed: D1.1 (K), R2.2
unnamed: D2.2 (A), R19.1, R20.1
unnamed: D5.1 (K1), R25.1
unnamed: D5.3 (K2), Q3.1 (C)
unnamed: F1.1, SW1.4
unnamed: J3.S, R1.1
unnamed: J4.S, R3.1
unnamed: J5.S, R4.1
unnamed: J6.T, R21.2
unnamed: J7.S, R5.1
unnamed: J8.S, R7.1
unnamed: J9.S, R8.1
unnamed: J10.T, R6.2
unnamed: J11.S, R9.1
unnamed: J12.S, R11.1
unnamed: J13.S, R12.1
unnamed: J14.S, R13.1
unnamed: J15.S, R14.1
unnamed: J16.S, R15.1
unnamed: J17.A5 (CC1), R24.2
unnamed: J17.B5 (CC2), R23.2
unnamed: J17.A9 (VBUS), J17.B9 (VBUS), SW1.5
unnamed: J19.S, J20.S, R16.2
unnamed: C16.2, JP1.1 (A), L1.2, TP1.1, U2.1 (FB)
unnamed: J6.R1, JP2.2 (B), R22.2
unnamed: J10.R1, JP3.2 (B), R10.2
unnamed: Q2.2 (B), R20.2
unnamed: Q2.1 (C), Q3.2 (B), R25.2
unnamed: Q3.3 (E), R27.1
unnamed: R10.1, R17.1, R22.1, U4.7
unnamed: C2.2, U2.6 (BST)
unnamed: C2.1, L1.1, U2.5 (SW)
unnamed: C17.2, R18.1, R30.2, R33.1, U4.3 (+)
unnamed: R6.1, R21.1, U4.1, U4.2 (-)
unnamed: R17.2, R18.2, U4.6 (-)
unnamed: FB3.1, U7.1 (+OUT_L)
unnamed: FB2.1, U7.16 (+OUT_R)
unnamed: FB4.1, U7.3 (-OUT_L)
unnamed: FB1.1, U7.14 (-OUT_R)
unnamed: R29.2, U7.7 (INL)
unnamed: R28.2, U7.10 (INR)
unnamed: C4.2, U7.8 (VREF)
VCC: C6.1, SW1.7, TP3.1, U2.2 (EN), U2.3 (IN)

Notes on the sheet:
reduce volume
Balanced Interpreter Out
set PAM gain to 0dB
reverse polarity protection
Battery status indicator
3.3V/2
RC filter 96 Hz
power supply

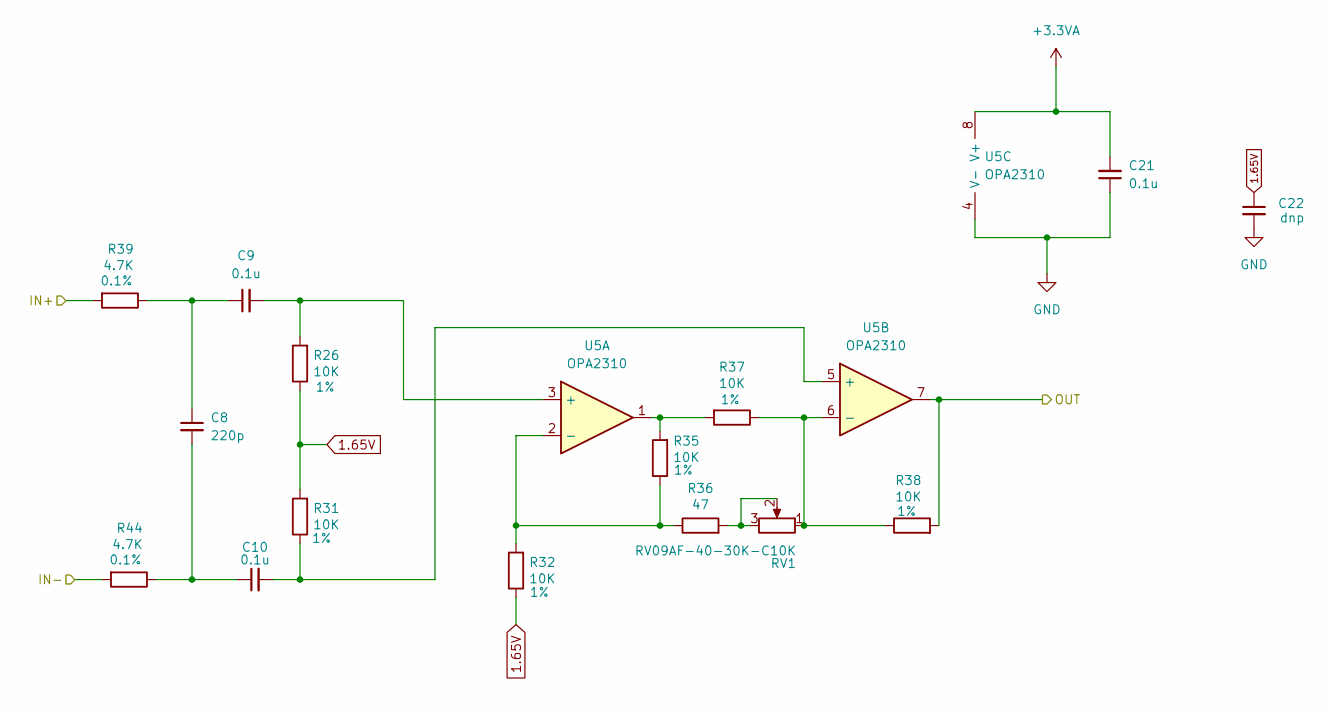
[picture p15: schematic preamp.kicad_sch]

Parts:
C8: 220p; C_Disc_D3.0mm_W2.0mm_P2.50mm
C9, C10, C21: 0.1u; C_Disc_D3.0mm_W2.0mm_P2.50mm
C22: dnp; C_Disc_D3.0mm_W2.0mm_P2.50mm
R26, R31, R32, R35, R37, R38: 10K; R_Axial_DIN0204_L3.6mm_D1.6mm_P5.08mm_Horizontal
R36: 47; R_Axial_DIN0204_L3.6mm_D1.6mm_P5.08mm_Horizontal
R39, R44: 4.7K; R_Axial_DIN0207_L6.3mm_D2.5mm_P7.62mm_Horizontal
RV1: RV09AF-40-30K-C10K; Potentiometer_Bourns_PTV09A-1_Single_Vertical
U5: OPA2310; SOIC-8_3.9x4.9mm_P1.27mm

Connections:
1.65V: C22.1, R26.1, R31.2, R32.1; also elsewhere on the board
+3.3VA: C21.2, U5.8 (V+); also elsewhere on the board
/Preamp Interpreter/IN+: R39.2; also elsewhere on the board
/Preamp Interpreter/IN-: R44.2; also elsewhere on the board
GND: C21.1, C22.2, U5.4 (V-); also elsewhere on the board
INT_OUT: R38.2, U5.7; also elsewhere on the board
unnamed: C8.1, C9.1, R39.1
unnamed: C8.2, C10.1, R44.1
unnamed: R35.2, R37.2, U5.1
unnamed: R36.2, RV1.2, RV1.3
unnamed: C9.2, R26.2, U5.3 (+)
unnamed: R32.2, R35.1, R36.1, U5.2 (-)
unnamed: C10.2, R31.1, U5.5 (+)
unnamed: R37.1, R38.1, RV1.1, U5.6 (-)

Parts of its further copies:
C12: 220p; C_Disc_D3.0mm_W2.0mm_P2.50mm
C13, C14, C27: 0.1u; C_Disc_D3.0mm_W2.0mm_P2.50mm
C24: dnp; C_Disc_D3.0mm_W2.0mm_P2.50mm
R40, R41, R42, R45, R47, R48: 10K; R_Axial_DIN0204_L3.6mm_D1.6mm_P5.08mm_Horizontal
R43, R49: 4.7K; R_Axial_DIN0207_L6.3mm_D2.5mm_P7.62mm_Horizontal
R46: 47; R_Axial_DIN0204_L3.6mm_D1.6mm_P5.08mm_Horizontal
RV2: RV09AF-40-30K-C10K; Potentiometer_Bourns_PTV09A-1_Single_Vertical
U6: OPA2310; SOIC-8_3.9x4.9mm_P1.27mm

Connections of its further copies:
1.65V: C24.1, R40.1, R41.2, R42.1; also elsewhere on the board
+3.3VA: C27.2, U6.8 (V+); also elsewhere on the board
/Preamp Floor/IN+: R43.2; also elsewhere on the board
/Preamp Floor/IN-: R49.2; also elsewhere on the board
/Preamp Floor/OUT: R48.2, U6.7; also elsewhere on the board
GND: C24.2, C27.1, U6.4 (V-); also elsewhere on the board
unnamed: C12.1, C13.1, R43.1
unnamed: C12.2, C14.1, R49.1
unnamed: R45.2, R47.2, U6.1
unnamed: R46.2, RV2.2, RV2.3
unnamed: C13.2, R40.2, U6.3 (+)
unnamed: R42.2, R45.1, R46.1, U6.2 (-)
unnamed: C14.2, R41.1, U6.5 (+)
unnamed: R47.1, R48.1, RV2.1, U6.6 (-)

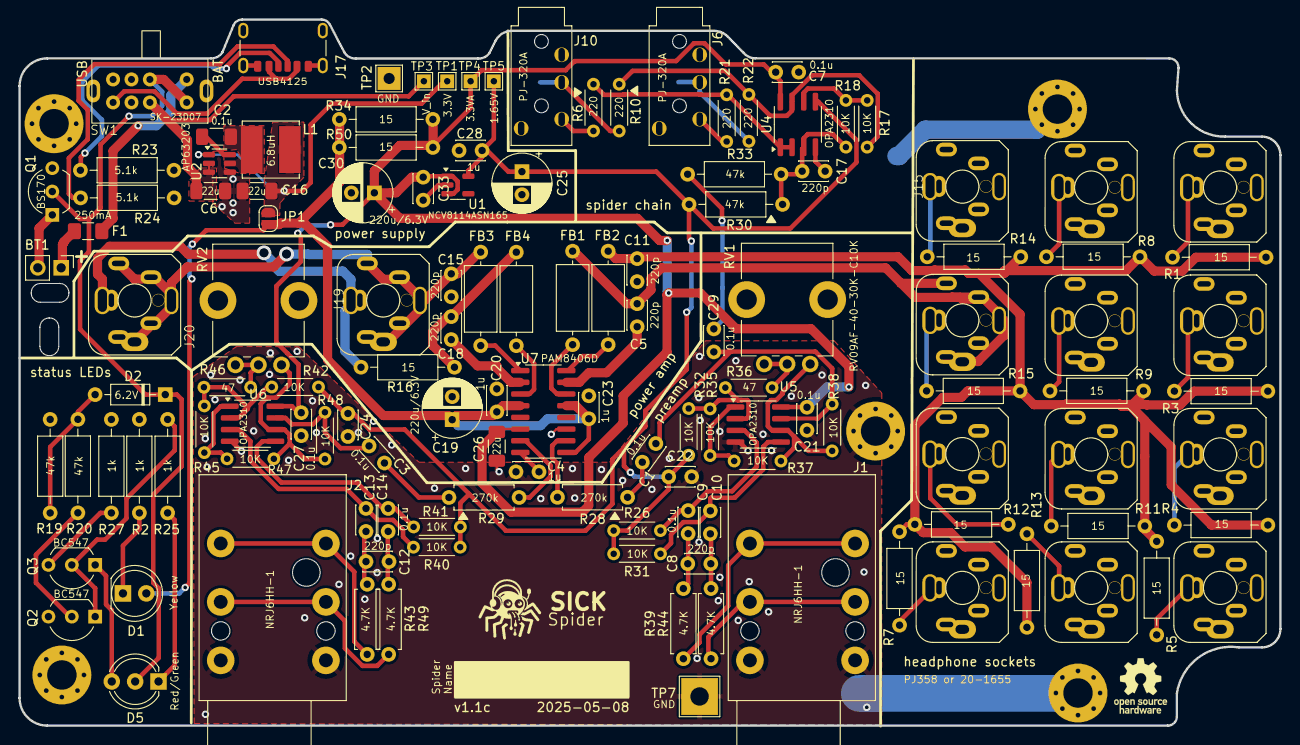
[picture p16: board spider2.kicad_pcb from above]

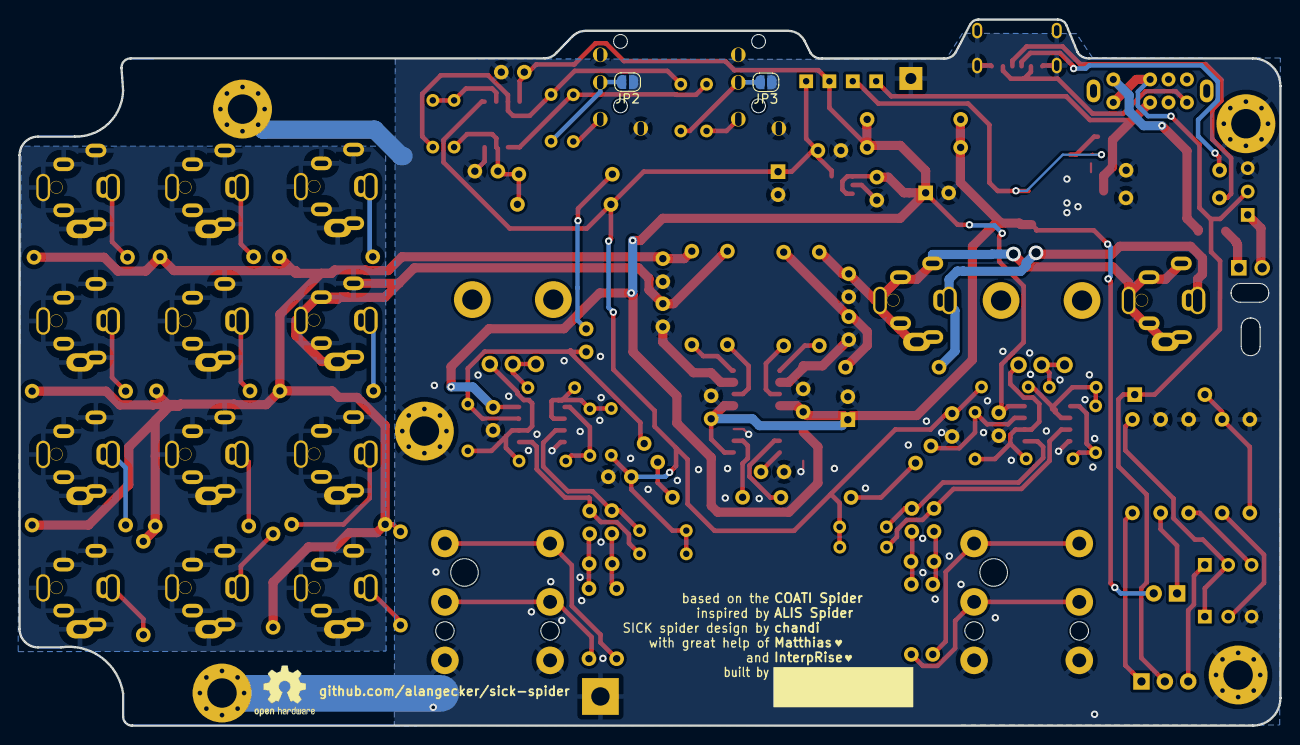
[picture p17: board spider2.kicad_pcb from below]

Board: 2 copper layers, 137.0 x 76.7 mm, 138 parts (3 on the bottom side), 79 nets.

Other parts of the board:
LOGO1: OSHW-Logo_5.7x6mm_SilkScreen
LOGO2: OSHW-Logo2_7.3x6mm_SilkScreen

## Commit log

2024-03-20 re-annotate schematic
    [preamp.kicad_sch, spider2.kicad_sch]
2024-03-25 incorporate review feedback on schematic + pcb design
    [preamp.kicad_sch, spider2.kicad_pcb, spider2.kicad_sch]
2024-03-26 3.3V step down, fixed wrong CMV on balanced out, additional SMD footprints
    [preamp.kicad_sch, spider2.kicad_pcb, spider2.kicad_sch]
2024-03-26 jumper for switching input jacks between GND and BIAS
    [preamp.kicad_sch, spider2.kicad_pcb, spider2.kicad_sch]
2024-03-26 specify parts and load simulation R
    [spider2.kicad_pcb, spider2.kicad_sch]
2024-03-26 credits on PCB
    [spider2.kicad_pcb]
2024-03-26 minor credits change
    [spider2.kicad_pcb]
2024-03-26 battery LEDs on same position as old on/off switch
    [spider2.kicad_pcb]
2024-03-27 implement review feedback
    [preamp.kicad_sch, spider2.kicad_pcb, spider2.kicad_sch]
2024-03-28 beautiful silkscreen design
    [spider2.kicad_pcb, spider2.kicad_sch]
2024-03-28 move kicad project into a folder
    [preamp.kicad_sch, spider2.kicad_pcb, spider2.kicad_sch]
2024-03-29 option for poti inversion and some missing connections
    [preamp.kicad_sch, spider2.kicad_pcb, spider2.kicad_sch]
2024-03-29 hybrid footprints for 3.5mm jacks
    [spider2.kicad_pcb, spider2.kicad_sch]
2024-03-30 final 2.0-proto
    [spider2--NPTH_map.gbr, spider2--PTH_map.gbr, spider2-B_Cu.gbl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]
2024-03-31 some cleanups
    [preamp.kicad_sch, spider2.kicad_pcb, spider2.kicad_sch]
2024-04-09 throw out not required pad (-30dB for line signals)
    the gain range via poti is sufficient enough for line and mics
    [preamp.kicad_sch, spider2.kicad_pcb]
2024-04-10 clean up not required components
    jumpers, some dnp components, etc.
    [preamp.kicad_sch, spider2.kicad_pcb, spider2.kicad_sch]
2024-04-10 slot for cable tieing the battery cable
    [spider2.kicad_pcb]
2024-04-10 bypass capacitor footprints smaller and closer
    [preamp.kicad_sch, spider2.kicad_pcb, spider2.kicad_sch]
2024-04-10 multiple changes
    - correct transistor footprints
    - swap led green/red
    - PAM input resistor
    - poti adjustments
    [preamp.kicad_sch, spider2.kicad_pcb, spider2.kicad_sch]
2024-04-11 reduce balanced out volume, 3.3V supply on SMD for lower emissions
    [preamp.kicad_sch, spider2.kicad_pcb, spider2.kicad_sch]
2024-04-11 rotate potentiometer by 180deg
    [preamp.kicad_sch, spider2.kicad_pcb, spider2.kicad_sch]
2024-04-11 silkscreen updates
    [spider2.kicad_pcb, spider2.kicad_sch]
2024-04-12 correct connector positions, some silkscreen updates
    [preamp.kicad_sch, spider2.kicad_pcb, spider2.kicad_sch]
2024-04-14 EMI improvements, allow PJ358 footprints, DRC fixes, poti changes
    [preamp.kicad_sch, spider2.kicad_pcb, spider2.kicad_sch]
2024-04-14 reduce BOM and more mechanical stable PJ358
    [preamp.kicad_sch, spider2.kicad_pcb, spider2.kicad_sch]
2024-04-14 poti: rotate 180deg and switch back to 100k with a reverse audio taper
    [preamp.kicad_sch, spider2.kicad_pcb]
2024-04-14 incoorperate matthias feedback
    - clearances
    - opamp swap
    - shorter traces
    - ...
    [preamp.kicad_sch, spider2.kicad_pcb, spider2.kicad_sch]
2024-04-15 minor changes (silkscreen, etc.)
    [spider2.kicad_pcb, spider2.kicad_sch]
2024-04-15 add some spare capacitors for EMI tests
    [preamp.kicad_sch, spider2.kicad_pcb]
2024-04-16 more EMI protection C's and poti inverting jumper
    [preamp.kicad_sch, spider2.kicad_pcb]
2024-04-16 last changes for 0.2 (testpoints, spare footprints,...)
    [preamp.kicad_sch, spider2.kicad_pcb, spider2.kicad_sch]
2024-04-26 redesigned MAX section with shorter traces, analog GND plane,...
    [preamp.kicad_sch, spider2.kicad_pcb, spider2.kicad_sch]
2024-04-26 revert separating ground planes
    maybe it leads to more issues than it solves
    [preamp.kicad_sch, spider2.kicad_pcb, spider2.kicad_sch]
2024-04-26 shorter traces + silkscreen updates
    [preamp.kicad_sch, spider2.kicad_pcb]
2024-04-27 clearer separation of sections, test marks,...
    [spider2.kicad_pcb, spider2.kicad_sch]
2024-04-29 some cleanups, cheaper MOSFET, datasheet links,
    [preamp.kicad_sch, spider2.kicad_pcb, spider2.kicad_sch]
2024-04-29 kibot: add Notes to BOM
2024-04-29 version 1.0
    [spider2--NPTH_map.gbr, spider2--PTH_map.gbr, spider2-B_Cu.gbl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]
2024-04-29 1.0: fixing wrong NRJ6HH-1 symbol
    [spider2--NPTH_map.gbr, spider2--PTH_map.gbr, spider2-B_Cu.gbl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]
2024-05-21 Fix wrong footprints for 20-1655 headphone jacks
2024-05-21 remove PJ359 footprints
    [spider2.kicad_pcb, spider2.kicad_sch]
2024-05-21 label switch positions (BAT / USB)
    [spider2.kicad_pcb]
2024-05-21 thicker traces to reduce the chance of irreparable damage by ripping them off
    [spider2.kicad_pcb]
2024-11-05 version 1.1
    - replace MAX4062 with own preamplifier circuit in order to avoid difficult TSOP soldering
    - easier solderable USB-C port
    - add linear regulator for stable 1.65V
    - replace LM358 with rail-to-rail and 3.3V compatible OPA2310 op amp
    - rounded corners
    [preamp.kicad_sch, spider2.kicad_pcb, spider2.kicad_sch]
2025-01-21 version 1.1
    [spider2--NPTH_map.gbr, spider2--PTH_map.gbr, spider2-B_Cu.gbl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]
2025-01-21 version 1.1b
    almost identical to 1.1, but
    - Limit Microphone Gain (R36,R46)
    - Battery fuse
    - More room for soldering USB port
    - Correct footprints for 0.1uF capacitors
    - Correct footprints for 4.7k resistor
    [preamp.kicad_sch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]
2025-05-08 version 1.1c
    - Fix misaligned traces at C16, C7 and C24
    - Add missing Silkscreen value for C29
    - Power switch 1mm further inside (sticks out quite a lot)
    - more clearence for headphone jacks so that it is more difficult to bridge them to GND
    [preamp.kicad_sch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]
2025-05-26 replace expensive switch (200MDP3T1B1M6QE, 3-4€) by a much cheaper on (SK-23D07, ~10ct)
    [spider2.kicad_pcb, spider2.kicad_sch]
2025-10-02 spider v1.2
    - replace expensive switch (200MDP3T1B1M6QE, 3-4€) by a much cheaper on (SK-23D07, ~10ct)
    [spider2--NPTH_map.gbr, spider2--PTH_map.gbr, spider2-B_Cu.gbl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]
